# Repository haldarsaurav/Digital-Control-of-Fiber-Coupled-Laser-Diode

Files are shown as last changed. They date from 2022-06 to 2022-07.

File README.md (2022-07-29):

# Digital Control of Fiber Coupled Laser Diode

Developing a new digital circuit using a micro-controller to drive Laser (LED1) replacing analog methods of curent control. 

<p align="center">
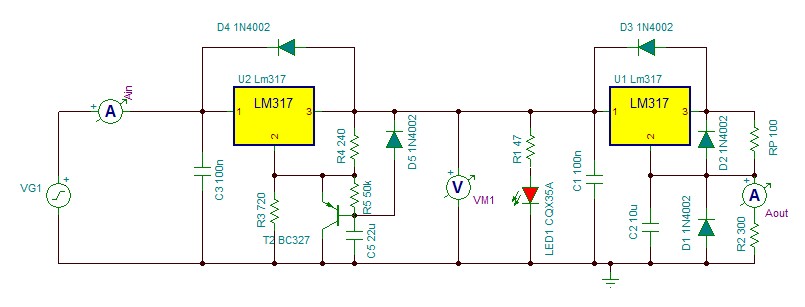
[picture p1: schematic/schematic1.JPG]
  
</p>

The Existing circuit we are trying to reeplicate digitally: 

<p align="center">
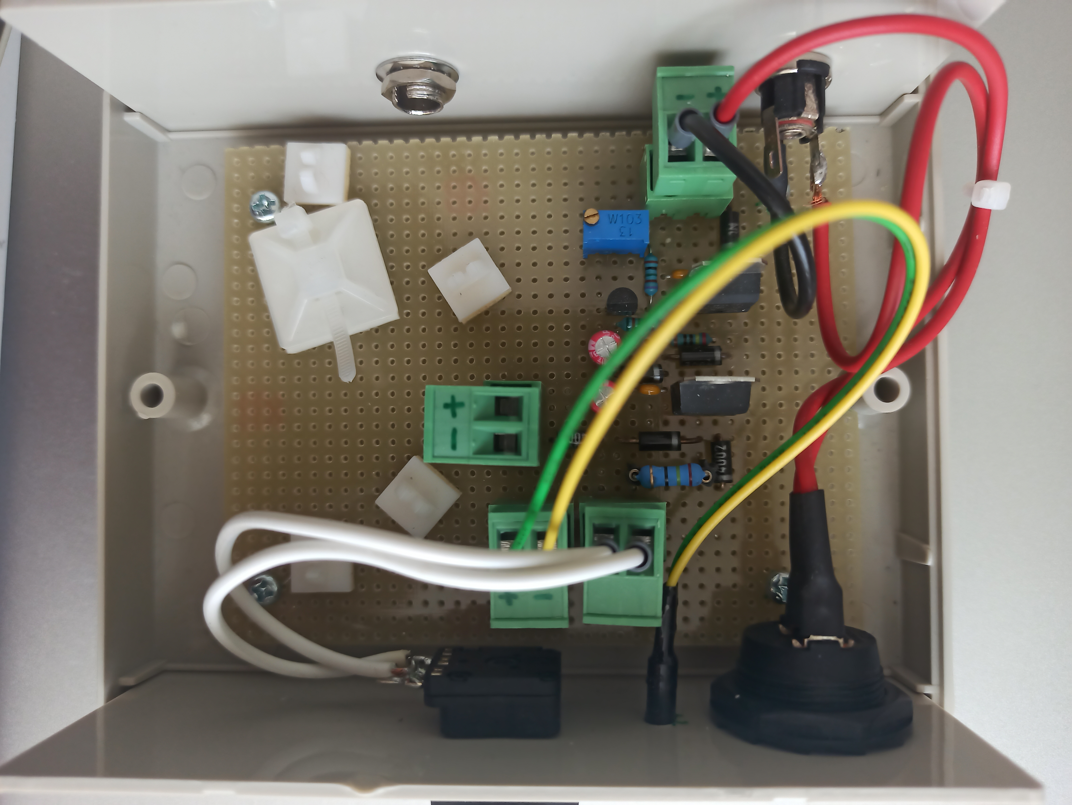
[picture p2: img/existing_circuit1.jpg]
  
</p>

<p align="center">
  
</p>

Some of our objectives :- 

<ul>
  <li>Controlling the current to a LASER thorugh digital means instead of  analog means (Variable Resistors)</li>
  <li>Reading the current drawn and power of the LASER dynamicvally using INA219 Current Sensor</li>
  <li>Interfacing an LCD to monitor the display the PWM value of micro-controller and the curreent and poweer drawn dynamically</li>
</ul>  

Additional improvent and additions

<ul>
  <li>Adding a temperature sensor to measure the ambient temperature</li>
  <li>Adding a bluetooth transreciever to control the curreent value remotely</li> 
  <li>Developing an app or webpage based GUI application</li>
  <li>Logging all the data recieved and store it on sd card or cloud</li>
  <li>Housing all the electronics in a approprite housing.</li>
</ul>  

## Prototyping the existing circuit

Made the circuit following the schematic to drive the LASER

<p align="center">
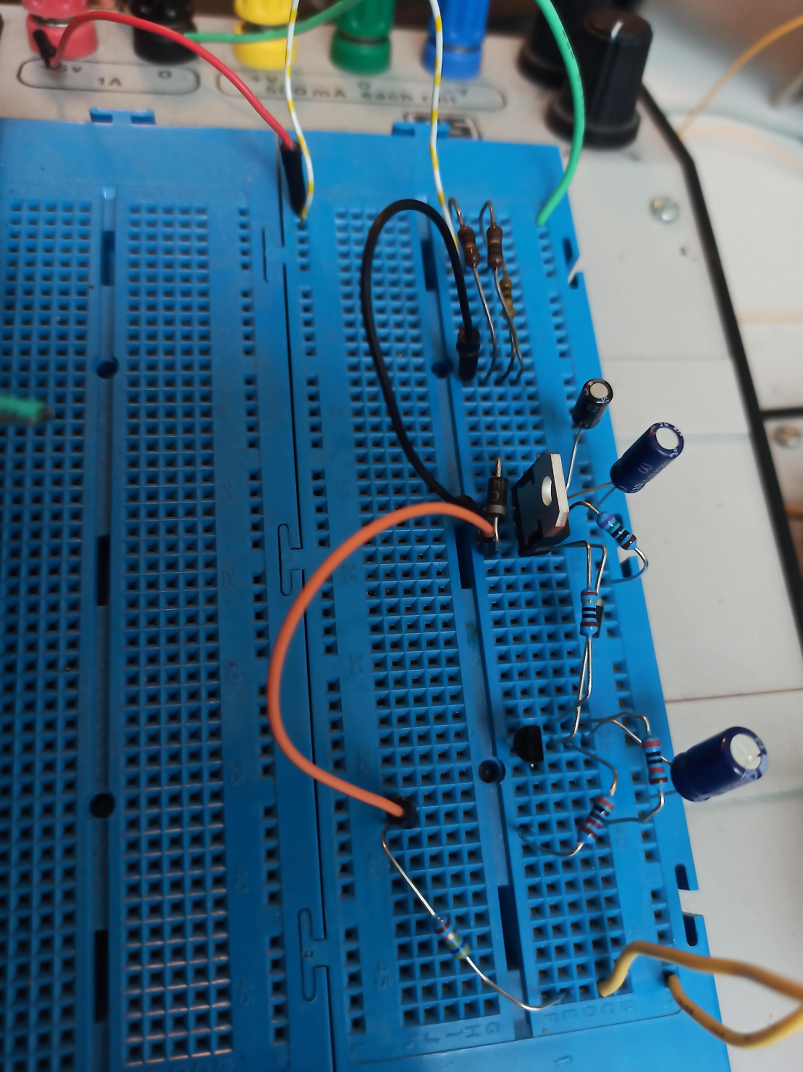
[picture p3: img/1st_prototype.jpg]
  
</p>

code snippet of sending increased PWM signals through A9 pin of Arduino 

    void loop() {
         analogWrite(9,100);                                           // Laser diode connected to pin A9
         delay(1000);
         analogWrite(9,150);
         delay(1000);
         analogWrite(9,200);
         delay(1000);
         analogWrite(9,250);
         delay(1000);
         analogWrite(9,0);
         delay(1000);
    }

## Intefaced the LCD to show any required data

<p align="center">
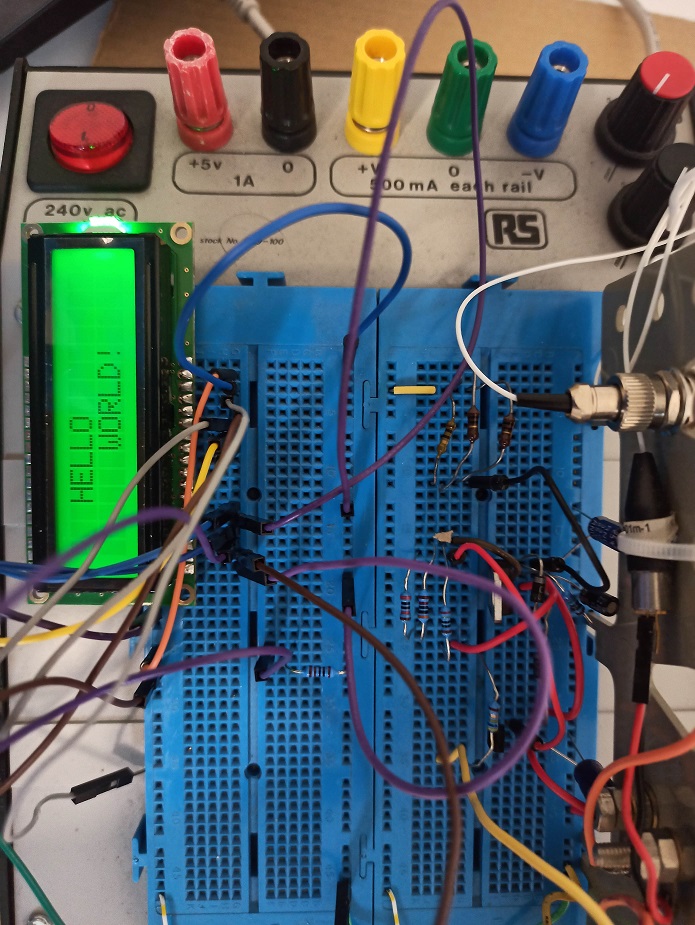
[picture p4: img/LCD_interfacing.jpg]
  
</p>

Code with LCD initialsed:

    // include the library code:

    #include <LiquidCrystal.h>                                     // initialize the library by associating any needed LCD interface pin

    const int rs = 12, en = 11, d4 = 5, d5 = 4, d6 = 3, d7 = 2;    // with the arduino pin number it is connected to

    LiquidCrystal lcd(rs, en, d4, d5, d6, d7);

    void setup() {                                                 // set up the LCD's number of columns and rows:

    lcd.begin(16, 2);

    }

    void loop() {
     analogWrite(9,100);                                           // Laser diode connected to pin A9
     delay(1000);
     analogWrite(9,150);
     delay(1000);
     analogWrite(9,200);
     delay(1000);
     analogWrite(9,250);
     delay(1000);
     analogWrite(9,0);
     delay(1000);

                                                               // LCD Message
    lcd.print("   HELLO       ");
    lcd.setCursor(0,1);                                        // Set the cursor for the second line( the second 1 after comma sets the cursor at the 2 or lower line).
    lcd.print("      WORLD "); 

    }

## Interfaced the INA219 Current sensor to measure the current value

<p align="center">
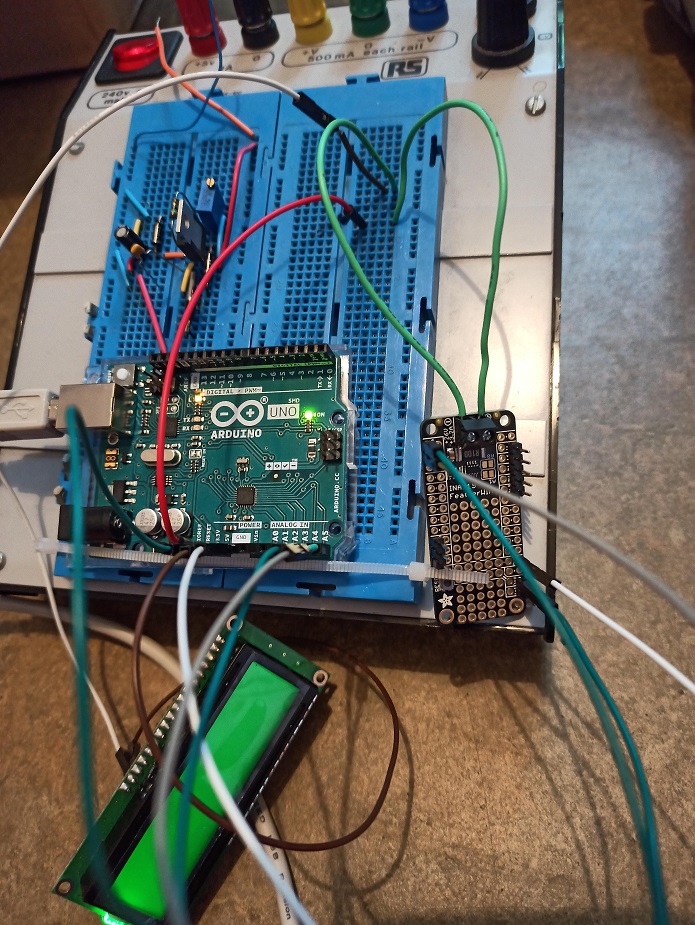
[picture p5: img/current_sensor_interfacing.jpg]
  
</p>

The vale from the INA219 using the LCD's LED as load :) (As I am doing this project Hochschule, I am quite restricted with parts)

<p align="center">
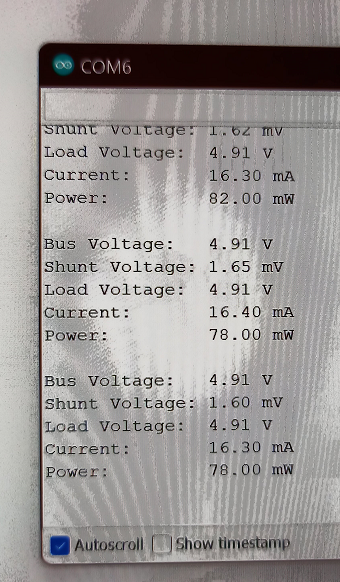
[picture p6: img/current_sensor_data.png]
  
</p>

Code for inteerfacing INA219 and measuring the current values

    #include <Wire.h>
    #include <Adafruit_INA219.h>

    Adafruit_INA219 ina219;

    void setup(void) 
    {
      Serial.begin(9600);
      while (!Serial) {
          // will pause Zero, Leonardo, etc until serial console opens
          delay(1);
      }

      uint32_t currentFrequency;

      Serial.println("Hello!");

      if (! ina219.begin()) {
        Serial.println("Failed to find INA219 chip");
        while (1) { delay(10); }
      }

      Serial.println("Measuring voltage and current with INA219 ...");
    }

    void loop(void) 
    {
      float shuntvoltage = 0;
      float busvoltage = 0;
      float current_mA = 0;
      float loadvoltage = 0;
      float power_mW = 0;

      shuntvoltage = ina219.getShuntVoltage_mV();
      busvoltage = ina219.getBusVoltage_V();
      current_mA = ina219.getCurrent_mA();
      power_mW = ina219.getPower_mW();
      loadvoltage = busvoltage + (shuntvoltage / 1000);

      Serial.print("Bus Voltage:   "); Serial.print(busvoltage); Serial.println(" V");
      Serial.print("Shunt Voltage: "); Serial.print(shuntvoltage); Serial.println(" mV");
      Serial.print("Load Voltage:  "); Serial.print(loadvoltage); Serial.println(" V");
      Serial.print("Current:       "); Serial.print(current_mA); Serial.println(" mA");
      Serial.print("Power:         "); Serial.print(power_mW); Serial.println(" mW");
      Serial.println("");

      delay(2000);
    }

Schematic for the entire plan and existing circuits which are already implemented, we can futher make the system more compact using an on-board ATMEGA328 IC.

<p align="center">
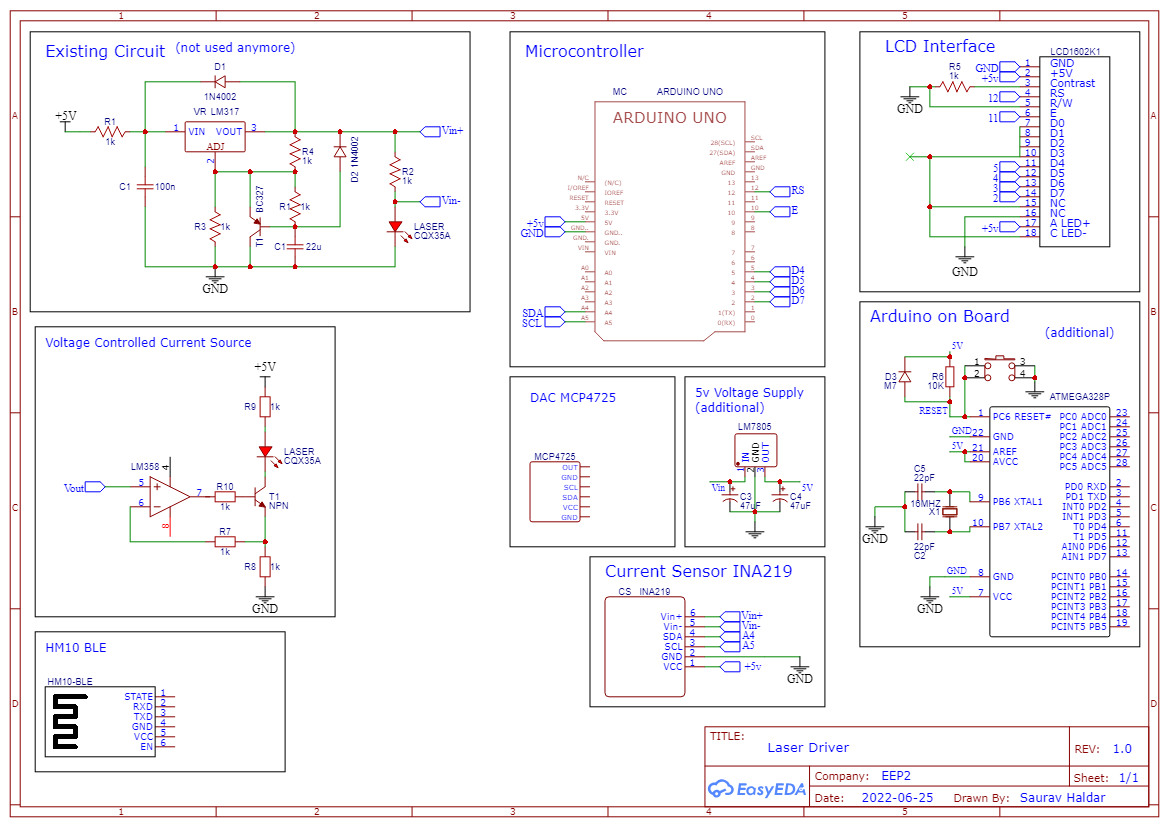
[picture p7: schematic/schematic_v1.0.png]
  
</p>

We plan to use MCP4725 to convert the analog PWM signals from Arduino to digital values then use that to drive a current controlled Op-amp circuit in a voltage followeer mode. 

Some of my simulations :-

<p align="center">
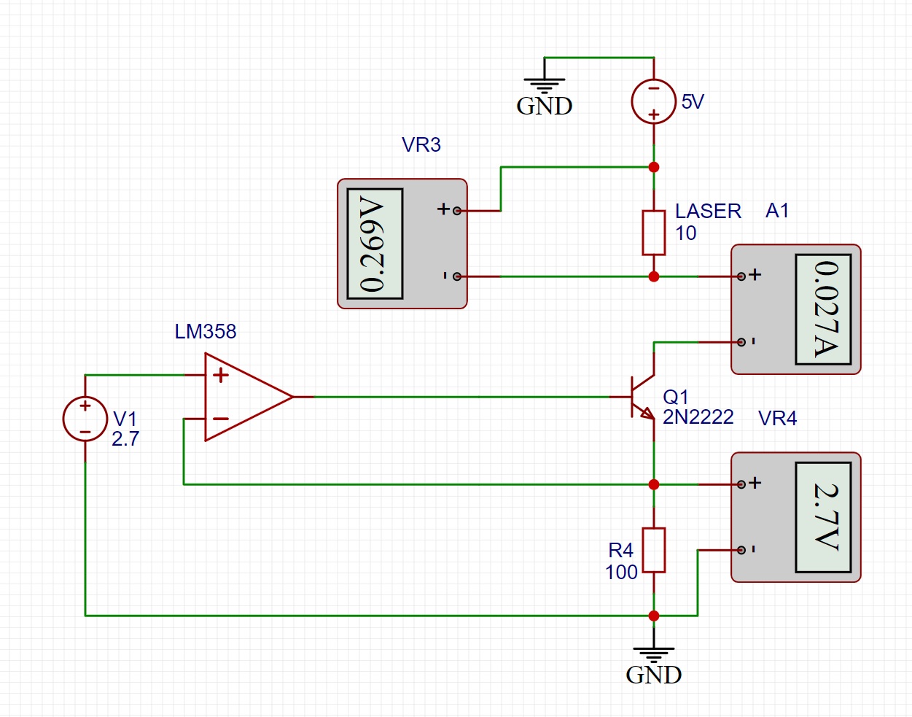
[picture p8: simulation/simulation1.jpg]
  
</p>
<p align="center">
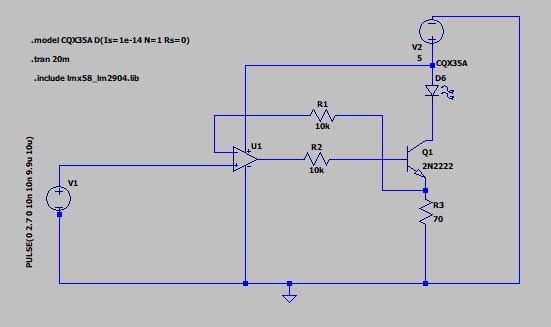
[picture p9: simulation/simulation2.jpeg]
  
</p>
<p align="center">
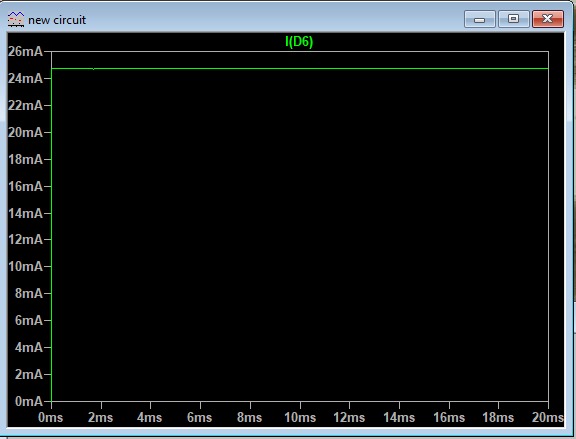
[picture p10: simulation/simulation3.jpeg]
  
</p>

and then use a HM10 Blueetooth module to control the system oveer bluetooth remotely.

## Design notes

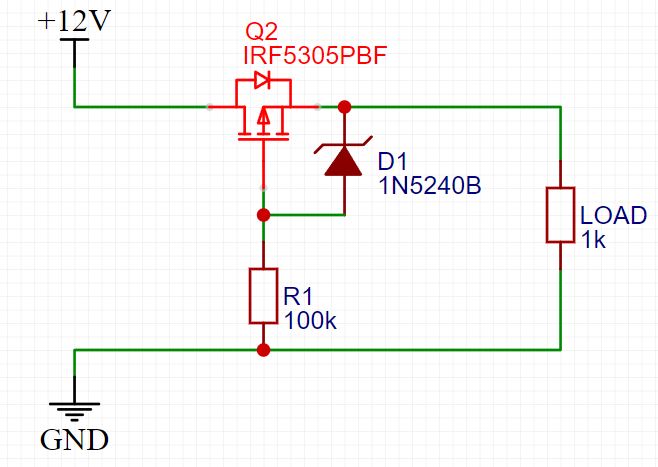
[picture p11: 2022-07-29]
schematic/protection_circuit.jpg

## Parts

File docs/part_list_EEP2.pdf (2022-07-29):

Part list for EEP2 Laser driver

1. MCP4725 DAC | 1 piece
2. HM-10 Bluetooth Module | 1 piece
3. OPAMP (LM358) | 1 piece
4. NPN Transistors (BC547) | 2 pieces
5. IRF540N | 1 piece
6. Resistors 750, 240, 47,100, 300 | 2 pieces each
7. Jumper Wires

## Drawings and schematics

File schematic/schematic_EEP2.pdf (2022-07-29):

## ADJ

# Existing Circuit

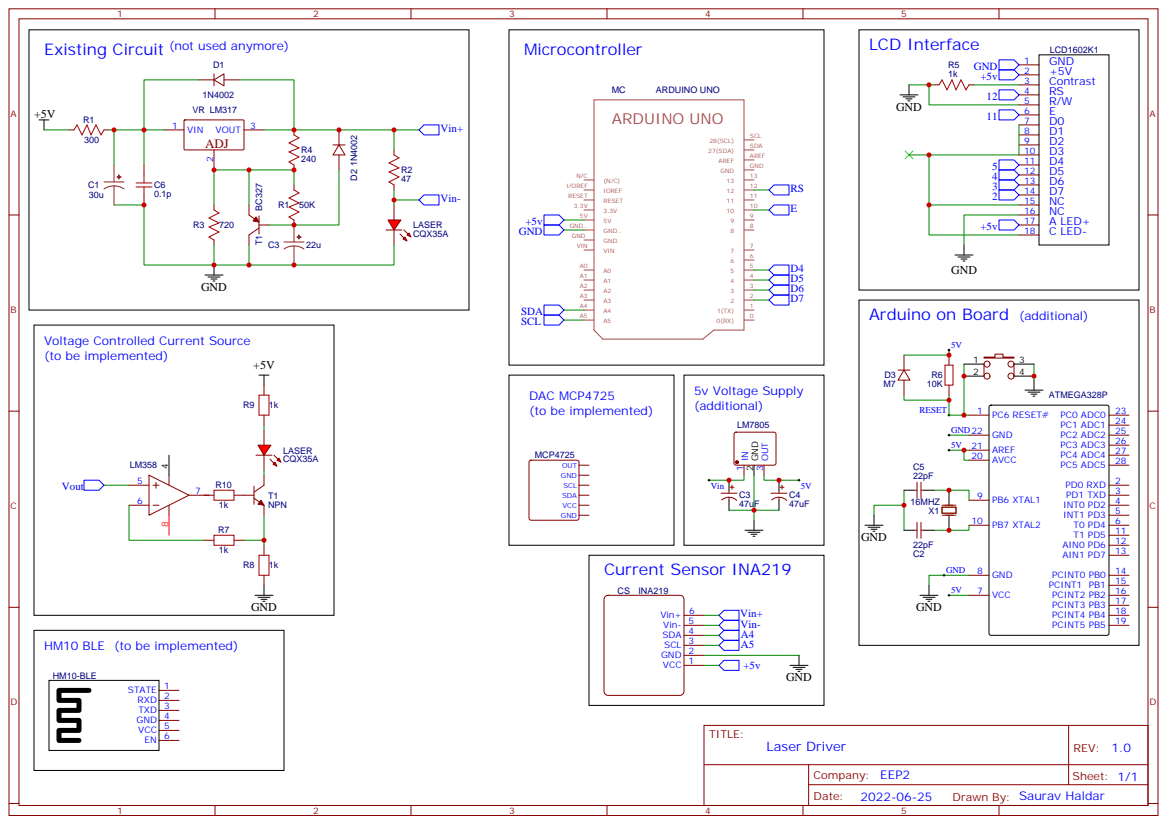
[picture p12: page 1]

Voltage Controlled Current Source
(to be implemented)

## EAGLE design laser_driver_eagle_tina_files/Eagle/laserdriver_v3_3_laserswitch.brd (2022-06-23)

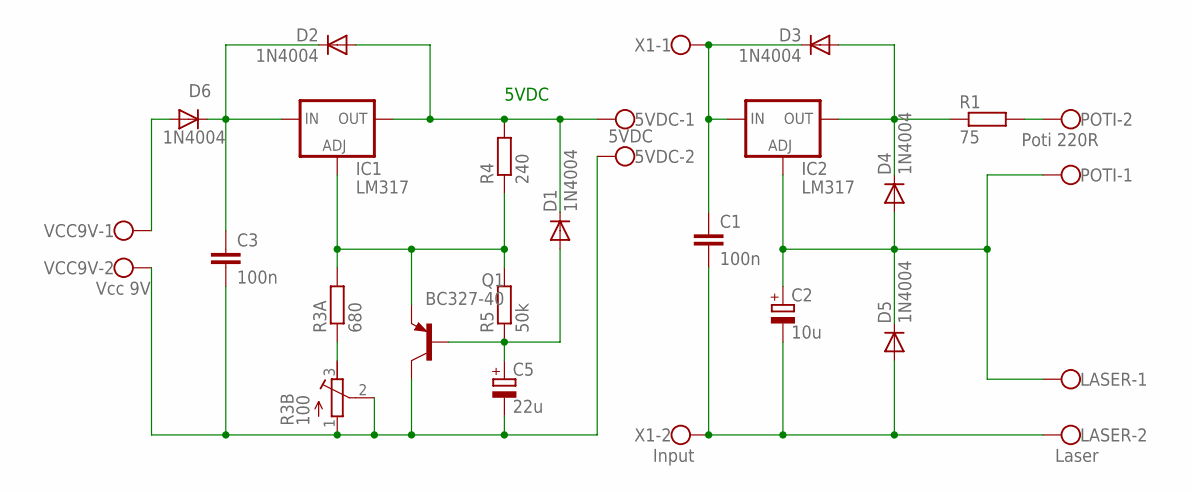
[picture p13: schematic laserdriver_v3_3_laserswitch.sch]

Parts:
5VDC: 5VDC; W237-102
C1, C3: 100n; C050-024X044
C2: 10u; E2-5
C5: 22u; E2-5
D1, D2, D3, D4, D5, D6: 1N4004; DO41-10
IC1, IC2: LM317; 317TS
LASER: Laser; W237-102
POTI: Poti 220R; W237-102
Q1: BC327-40; TO92-EBC
R1: 75; 0207/7
R3A: 680; 0207/7
R3B: 100; RTRIM3296W
R4: 240; 0207/7
R5: 50k; 0207/7
VCC9V: Vcc 9V; W237-102
X1: Input; W237-102

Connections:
unnamed: 5VDC.1, D1.C, D2.A, IC1.2 (OUT), R4.2
unnamed: C2.+, D4.A, D5.C, IC2.1 (ADJ), LASER.1, POTI.1
unnamed: D3.A, D4.C, IC2.2 (OUT), R1.1
unnamed: POTI.2, R1.2
unnamed: C5.+, D1.A, Q1.B, R5.1
unnamed: D6.A, VCC9V.1
unnamed: C3.1, D2.C, D6.C, IC1.3 (IN)
unnamed: R3A.1, R3B.3 (E)
unnamed: 5VDC.2, C3.2, C5.-, Q1.C, R3B.1 (A), R3B.2 (S), VCC9V.2
unnamed: C1.1, D3.C, IC2.3 (IN), X1.1
unnamed: C1.2, C2.-, D5.A, LASER.2, X1.2
unnamed: IC1.1 (ADJ), Q1.E, R3A.2, R4.1, R5.2

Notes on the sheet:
5VDC

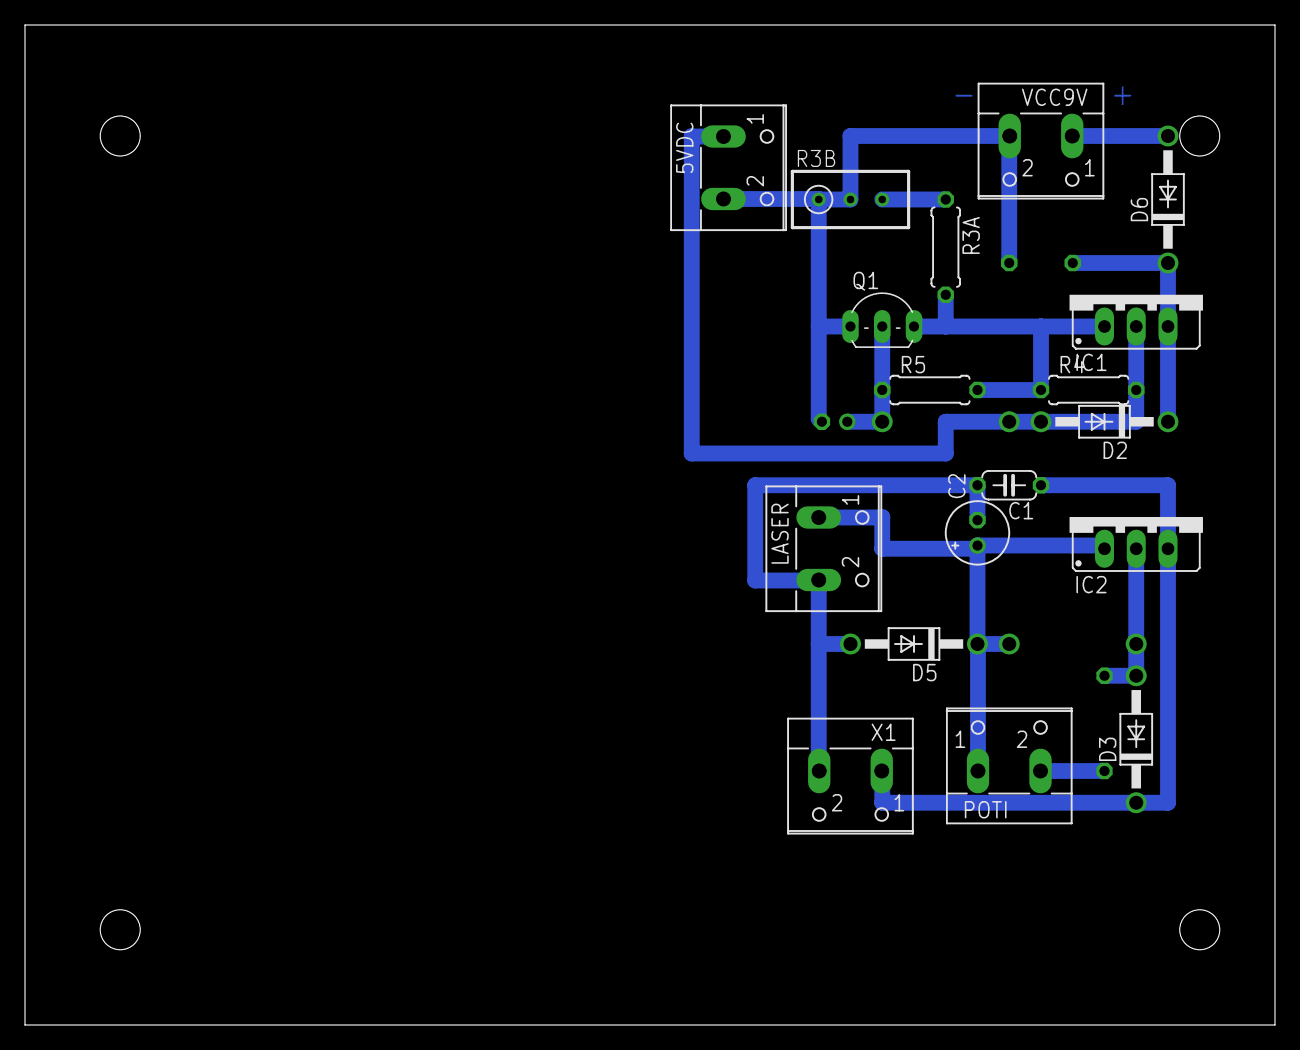
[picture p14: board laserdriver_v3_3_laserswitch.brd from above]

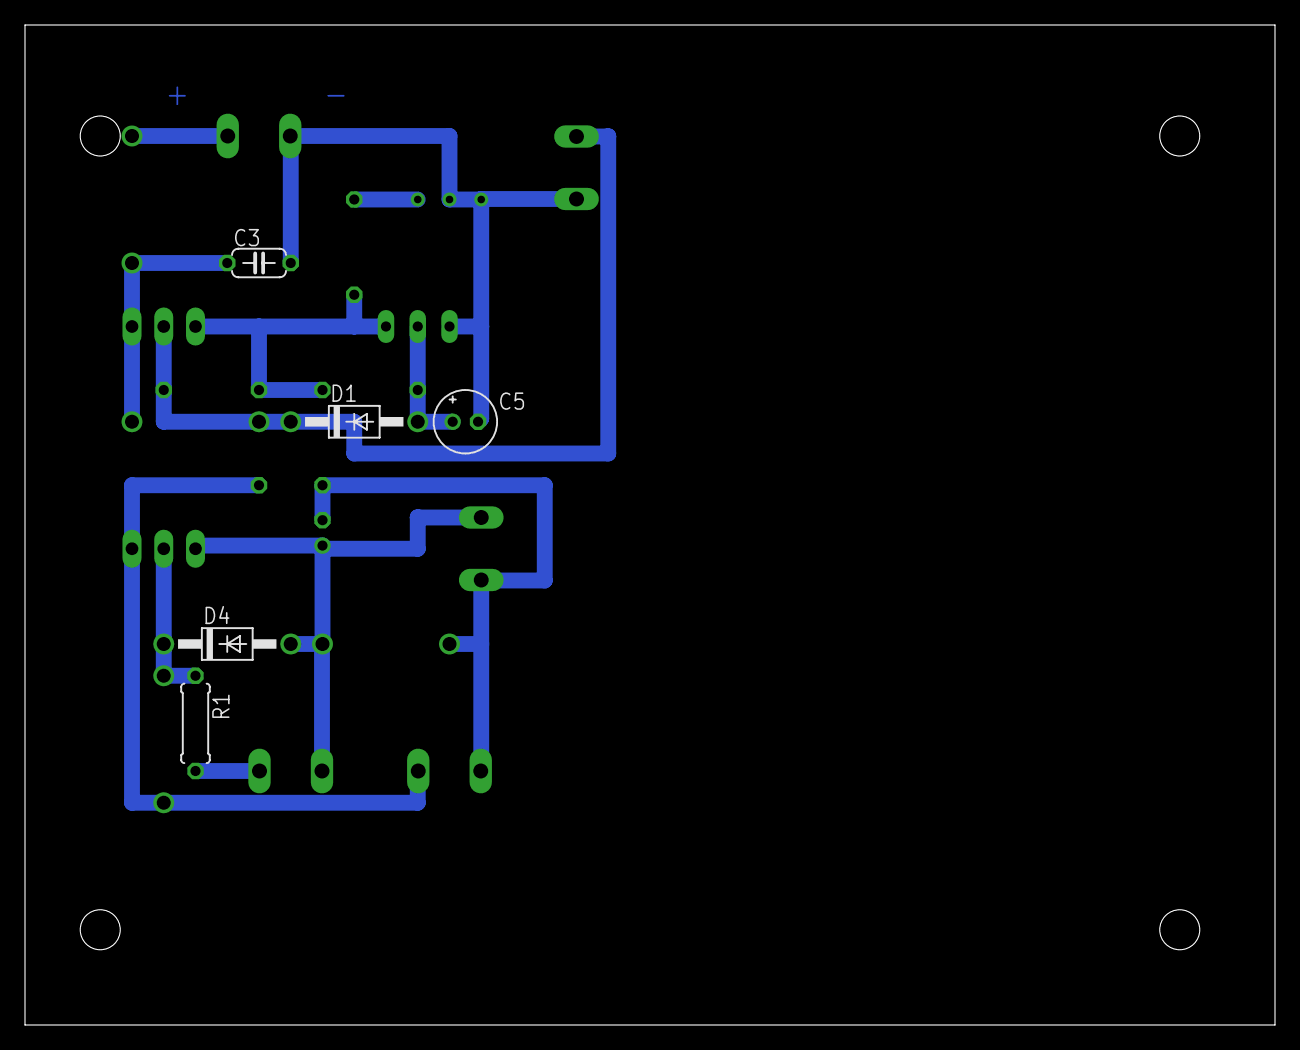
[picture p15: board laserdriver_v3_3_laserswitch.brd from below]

Board: 2 copper layers, 100.0 x 80.0 mm, 23 parts (5 on the bottom side), 12 nets.

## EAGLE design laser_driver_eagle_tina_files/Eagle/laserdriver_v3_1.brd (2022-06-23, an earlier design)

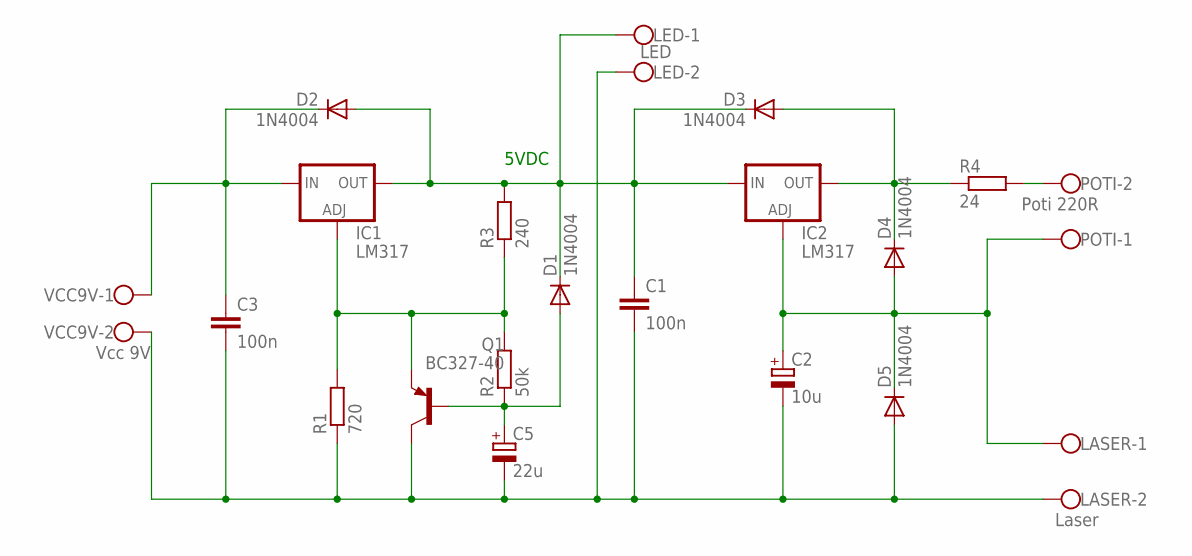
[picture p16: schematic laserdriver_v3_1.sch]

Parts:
C1, C3: 100n; C050-024X044
C2: 10u; E2-5
C5: 22u; E2-5
D1, D2, D3, D4, D5: 1N4004; DO41-10
IC1, IC2: LM317; 317TS
LASER: Laser; W237-102
LED: LED; W237-102
POTI: Poti 220R; W237-102
Q1: BC327-40; TO92-EBC
R1: 720; 0207/7
R2: 50k; 0207/7
R3: 240; 0207/7
R4: 24; 0207/7
VCC9V: Vcc 9V; W237-102

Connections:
unnamed: C1.1, D1.C, D2.A, D3.C, IC1.2 (OUT), IC2.3 (IN), LED.1, R3.2
unnamed: C2.+, D4.A, D5.C, IC2.1 (ADJ), LASER.1, POTI.1
unnamed: D3.A, D4.C, IC2.2 (OUT), R4.1
unnamed: POTI.2, R4.2
unnamed: C5.+, D1.A, Q1.B, R2.1
unnamed: C3.1, D2.C, IC1.3 (IN), VCC9V.1
unnamed: C1.2, C2.-, C3.2, C5.-, D5.A, LASER.2, LED.2, Q1.C, R1.1, VCC9V.2
unnamed: IC1.1 (ADJ), Q1.E, R1.2, R2.2, R3.1

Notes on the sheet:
5VDC

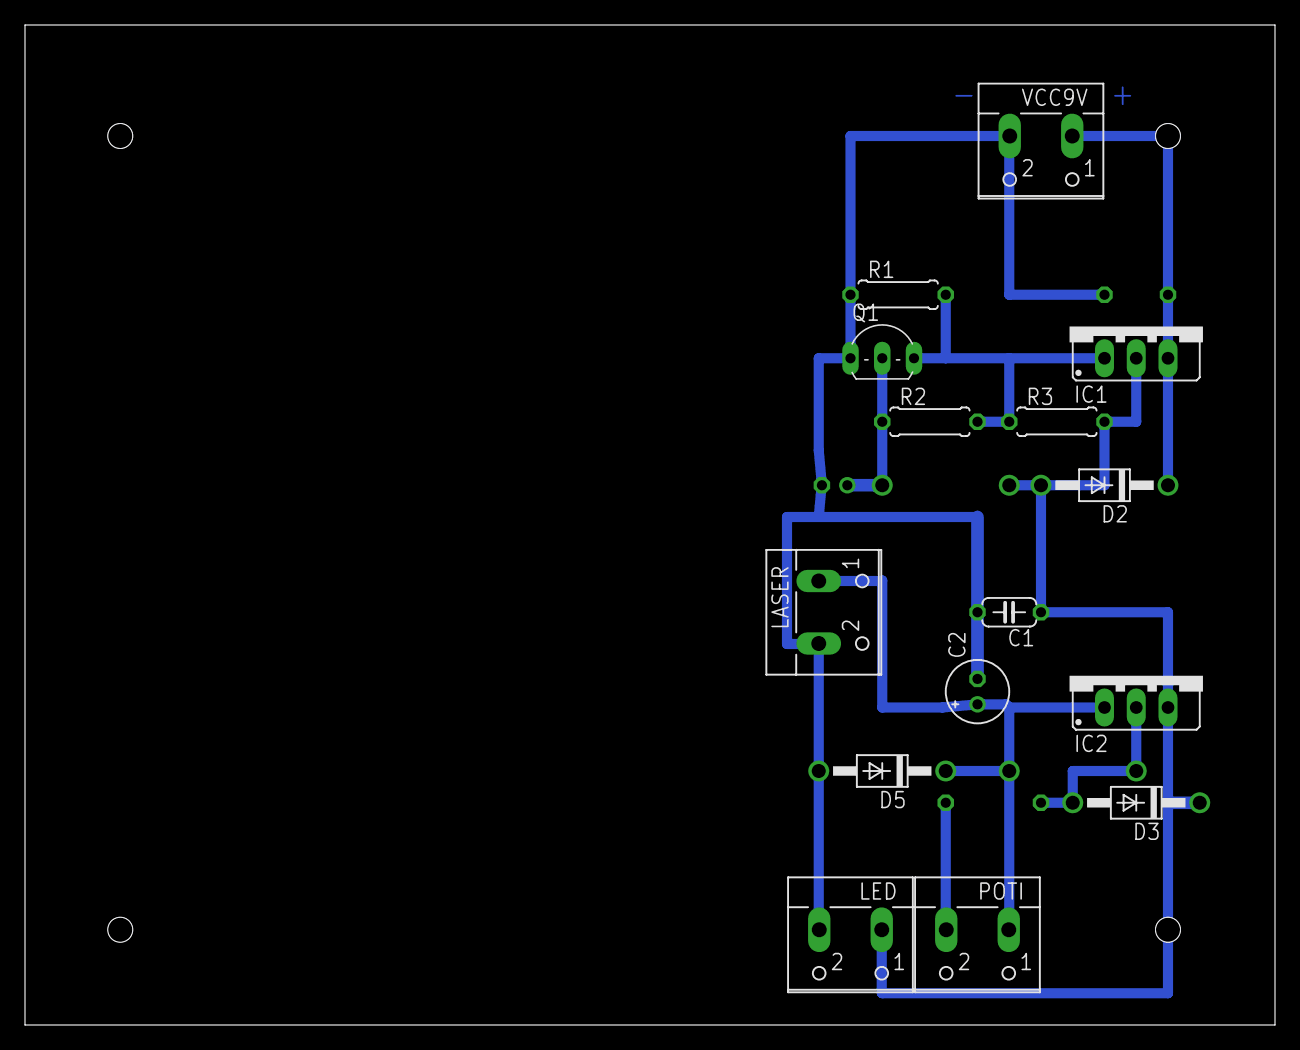
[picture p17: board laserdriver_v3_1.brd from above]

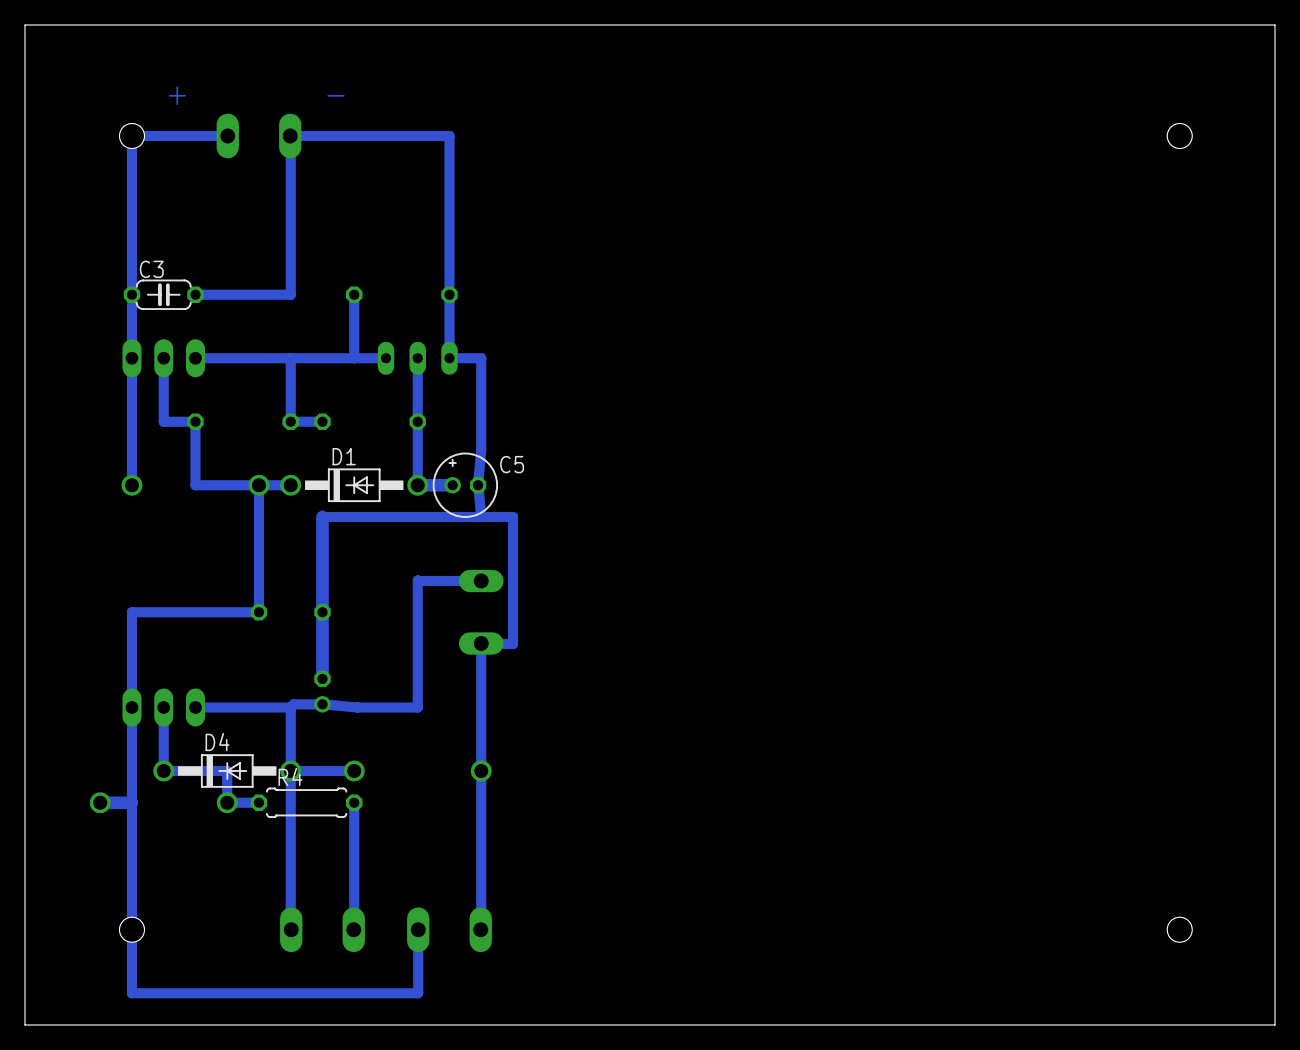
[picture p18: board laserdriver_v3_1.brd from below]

Board: 2 copper layers, 100.0 x 80.0 mm, 20 parts (5 on the bottom side), 8 nets.

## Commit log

2022-06-23 added the files
    [laserdriver_v3_1.brd, laserdriver_v3_1.sch, laserdriver_v3_2.brd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]
2022-06-23 some rearrangements
    [laserdriver_v3_1.brd, laserdriver_v3_1.sch, laserdriver_v3_2.brd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]
2022-06-25 added current sensor code
2022-06-26 folder rearranged
    [laserdriver_v3_1.brd, laserdriver_v3_1.sch, laserdriver_v3_2.brd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]
2022-07-29 added pics of existing circuit
2022-07-29 added schematic pdf
